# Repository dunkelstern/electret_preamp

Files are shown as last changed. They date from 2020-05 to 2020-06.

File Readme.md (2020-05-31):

# Electret Microphone Preamp

This design is purely based on [Texas Instruments Single-Supply, Electret Microphone Pre-Amplifier Reference Design by John Caldwell](http://www.ti.com/lit/ug/tidu765/tidu765.pdf?ts=1590780945605)

The Jupyter notebook is basically a interactive Version of that reference design PDF. I claim no copyright on this.

## What you will find here

### Jupyter Notebook

The included Jupyter Notebook is an interactive version of the reference design PDF from Texas instruments. You can
play with all values and let the program re-calculate all relevant values to be used in your own design.

There are some areas that will be most important:

- Operating Voltage of the Preamp

Operating Voltage

- Parameters of the Microphone capsule in use

Microphone parameters

- Acceptable high-frequency attenuation

Acceptable Attenuation at high frequencies

- Acceptable low-frequency cutoff in output highpass filter

Output capacity

- The List of passive component values

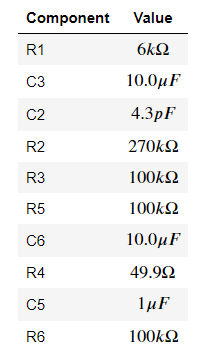
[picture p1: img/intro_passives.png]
Passives


- The Op-Amp parameters to look out for

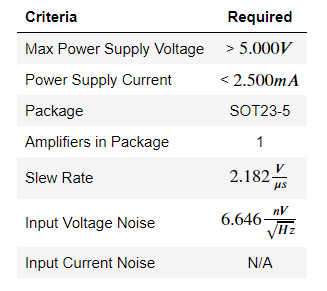
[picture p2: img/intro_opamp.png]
Op-Amp Parameters


### LT Spice simulation

I have simulated the circuit in LTSpice with some different Op-Amps I had in stock.
I deviated from the `270k` resistor in the Op-Amp feedback loop and opted for a `180k` value. This
means the amplification of the Op-Amp will not reach `0dB` (max. seems to be around `-1.8dB`) but the circuit seems
to run more stable at that amplification.

Here are some bode-plots of the frequency response for some tested Op-Amps:

#### OP07

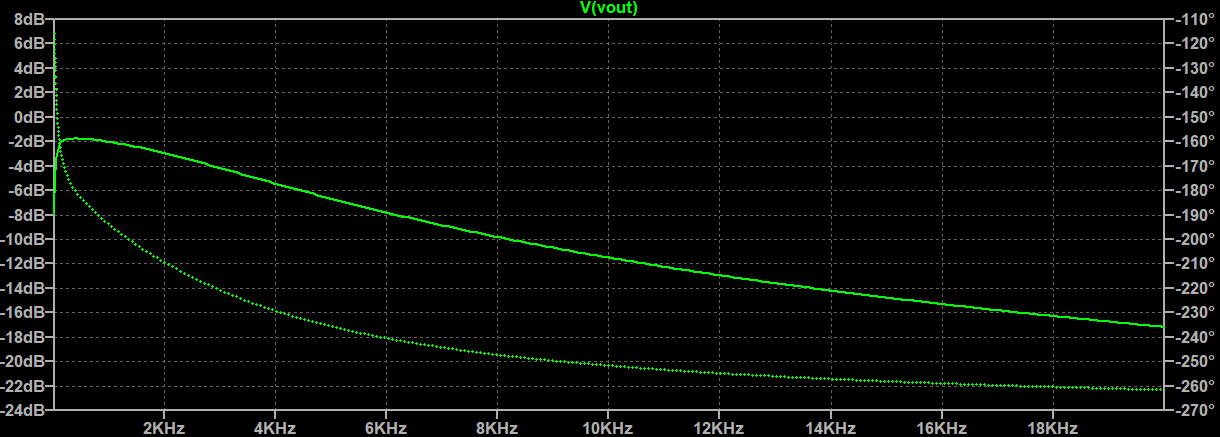
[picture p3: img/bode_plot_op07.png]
Bode plot for OP07


The OP07 is the worst possible of the bunch. The bad response is a product of the sub-optimal slew rate of 0.3V per uS.
Additionally this Op-Amp will add noise to the signal as it's input voltage noise is around . Ideally
it should be below  as we can see in the calulations.

#### TL072

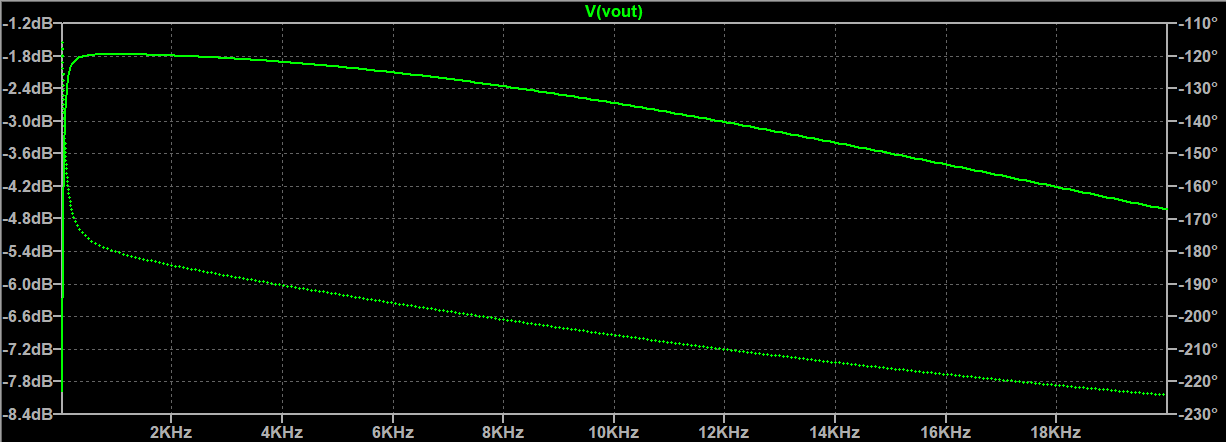
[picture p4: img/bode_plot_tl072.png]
Bode plot for TL072


The TL072 is a bit better than the OP07. The slew rate of 16V/uS is at least enough.
This Op-Amp will add a lot of noise to the signal as it's input voltage noise is around . Ideally
it should be below  as we can see in the calulations.

#### NE5532

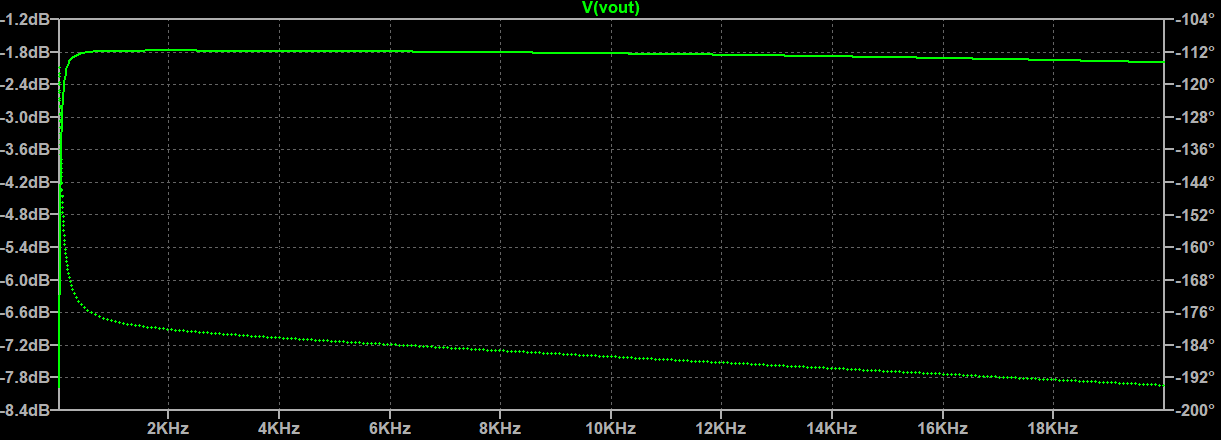
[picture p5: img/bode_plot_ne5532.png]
Bode plot for NE5532


The NE5532 is really good at this. All parameters are within the parameter range we calculated.

#### LM318

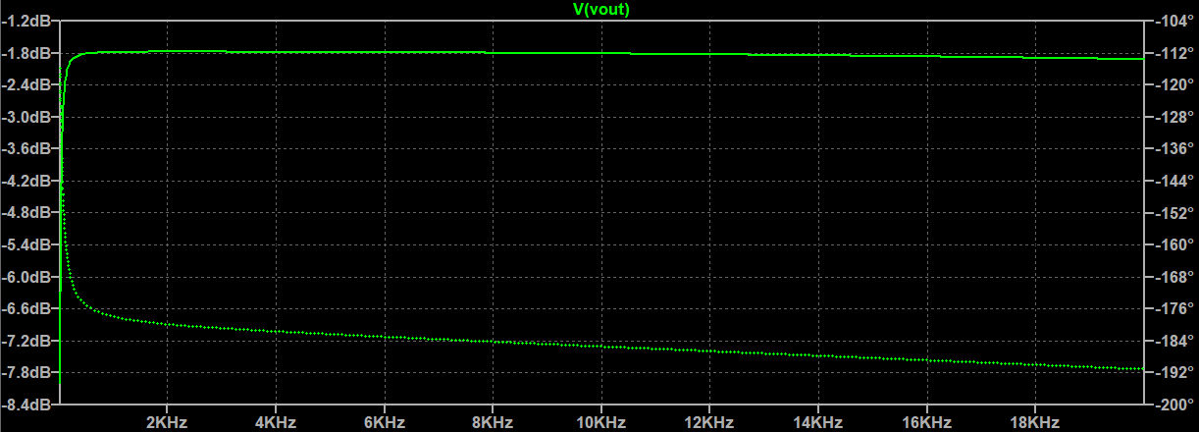
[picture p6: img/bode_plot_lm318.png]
Bode plot for LM318


You can see why the LM318 is used for these applications a lot, as it is a dedicated Audio-Op-Amp the response from
this thing is the best of the bunch.

**Attention**: The `LM318` needed `5.3V` operating voltage to actually do anything in the simulation, I have not
verified if this is an artifact of the simulation or an actual problem!

### KiCAD design

The KiCAD design is based on surface mount components to save as much space as possible. You could use tantalum
capacitors instead of the electrolyte I used here, but they are expensive and I don't have them in stock.

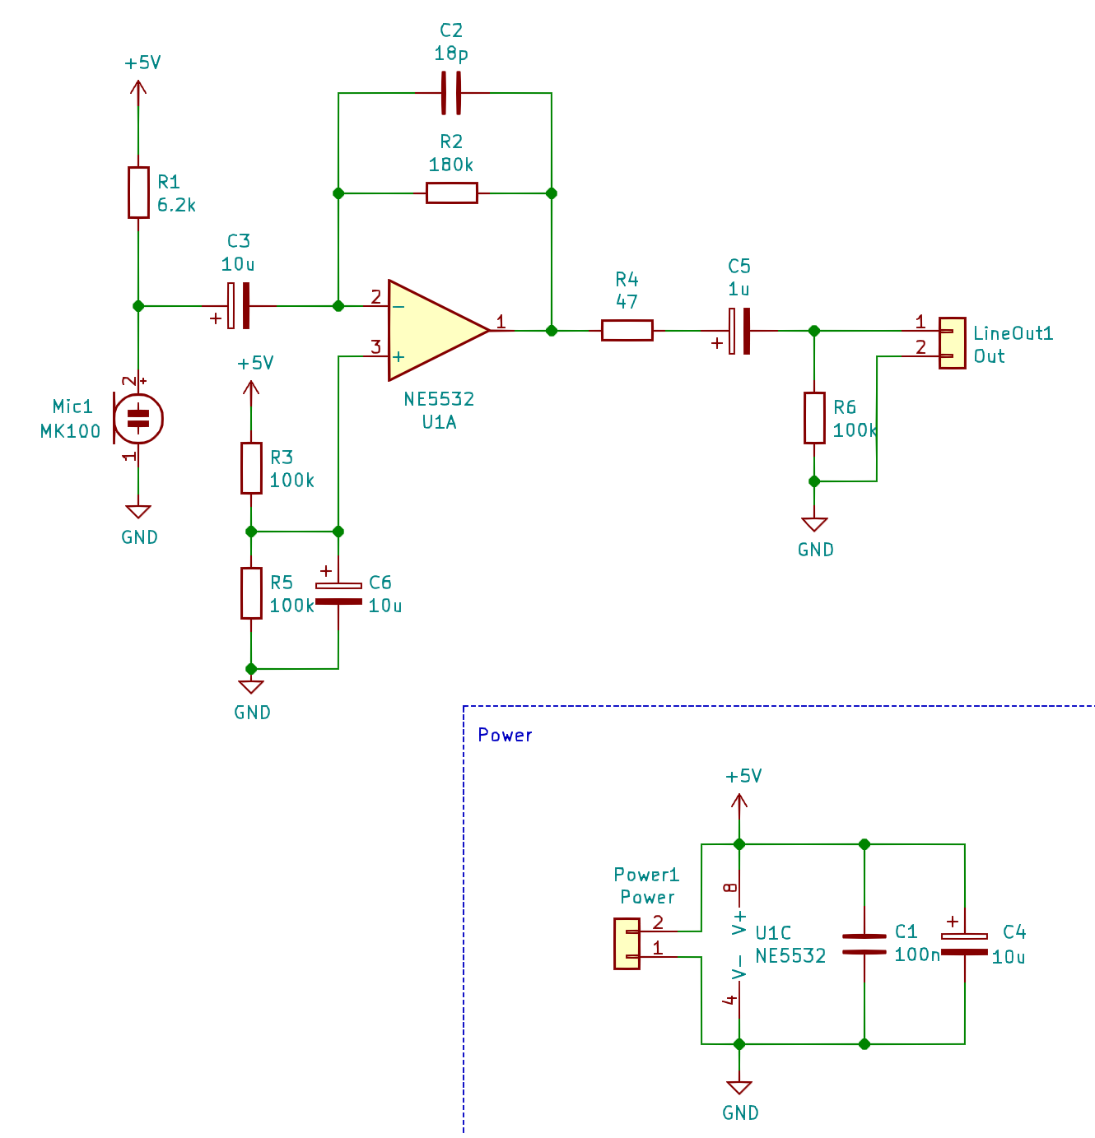
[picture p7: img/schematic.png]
KiCAD schematic


The board design is optimized for space and to be single sided as it is easier to prototype this way.
I will probably add a better two sided design in the future which will be optimized for noise performance and
will probably get even smaller (but I have to order the PCBs then)

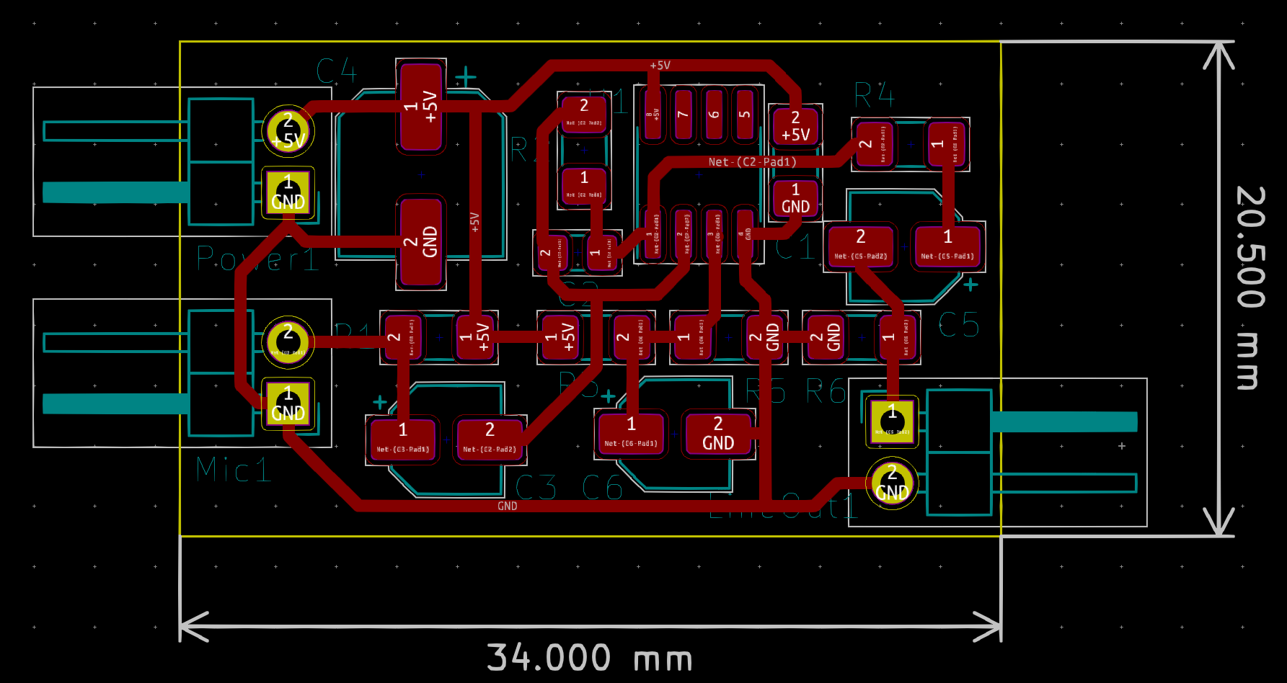
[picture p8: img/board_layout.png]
KiCAD board layout


This is what the board looks like rendered, I will add a photo of the finished product when I have built one.

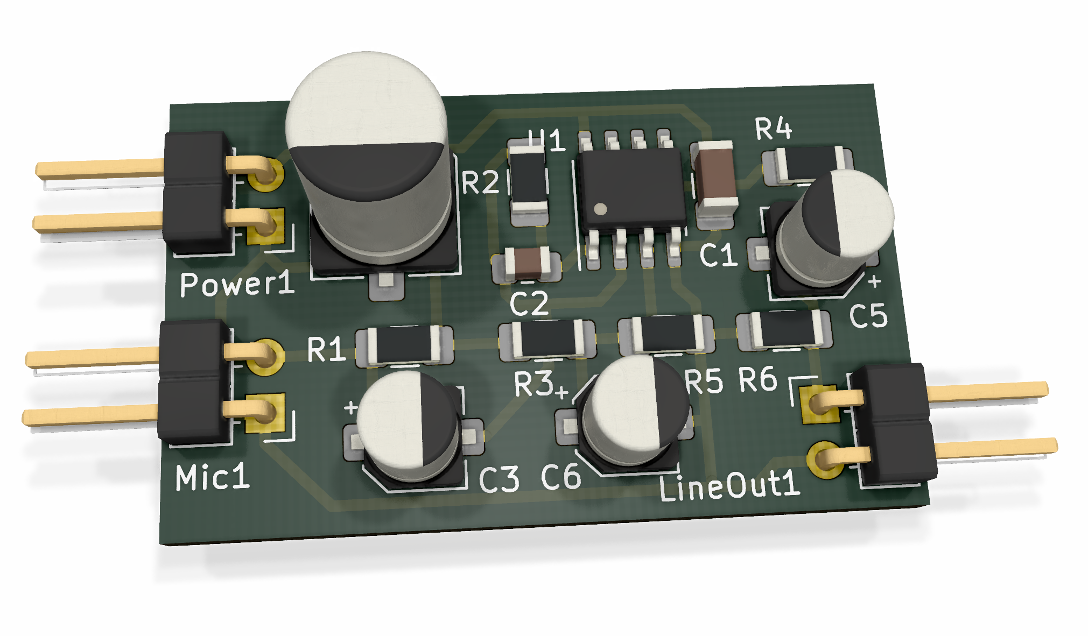
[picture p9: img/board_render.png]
KiCAD board render


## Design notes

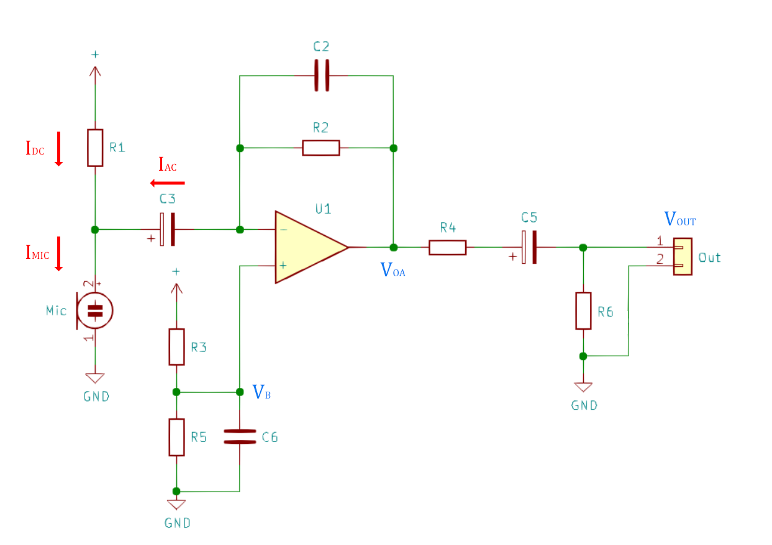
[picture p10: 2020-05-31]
img/schematic_novalues.png

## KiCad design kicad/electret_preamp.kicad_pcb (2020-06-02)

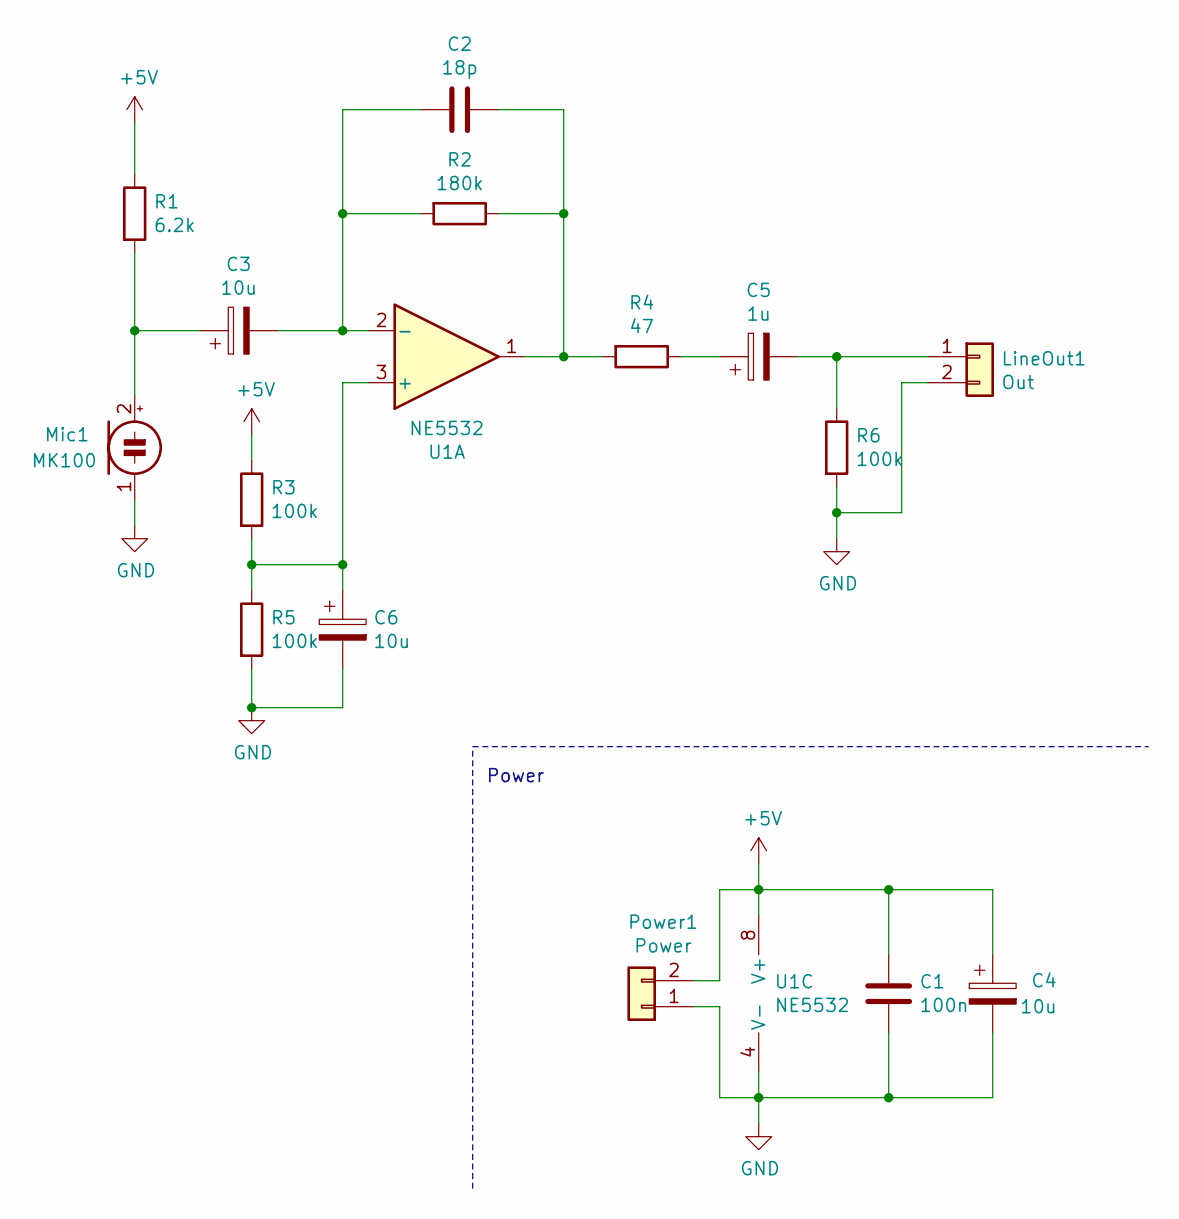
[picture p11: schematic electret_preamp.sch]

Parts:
C1: 100n; C_1210_3225Metric_Pad1.42x2.65mm_HandSolder
C2: 18p; C_0805_2012Metric_Pad1.15x1.40mm_HandSolder
C3, C6: 10u; CP_Elec_4x5.8
C4: 10u; CP_Elec_6.3x9.9
C5: 1u; CP_Elec_4x5.8
LineOut1: Out; PinHeader_1x02_P2.54mm_Horizontal
Mic1: MK100; PinHeader_1x02_P2.54mm_Horizontal
Power1: Power; PinHeader_1x02_P2.54mm_Horizontal
R1: 6.2k; R_1210_3225Metric_Pad1.42x2.65mm_HandSolder
R2: 180k; R_1210_3225Metric_Pad1.42x2.65mm_HandSolder
R3, R5, R6: 100k; R_1210_3225Metric_Pad1.42x2.65mm_HandSolder
R4: 47; R_1210_3225Metric_Pad1.42x2.65mm_HandSolder
U1: NE5532; SOIC-8_3.9x4.9mm_P1.27mm

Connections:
+5V: C1.2, C4.1, Power1.2, R1.1, R3.1, U1.8 (V+)
GND: C1.1, C4.2, C6.2, LineOut1.2, Mic1.1 (-), Power1.1, R5.2, R6.2, U1.4 (V-)
unnamed: C2.1, R2.1, R4.2, U1.1
unnamed: C2.2, C3.2, R2.2, U1.2 (-)
unnamed: C3.1, Mic1.2 (+), R1.2
unnamed: C5.1, R4.1
unnamed: C5.2, LineOut1.1, R6.1
unnamed: C6.1, R3.2, R5.1, U1.3 (+)

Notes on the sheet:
Power

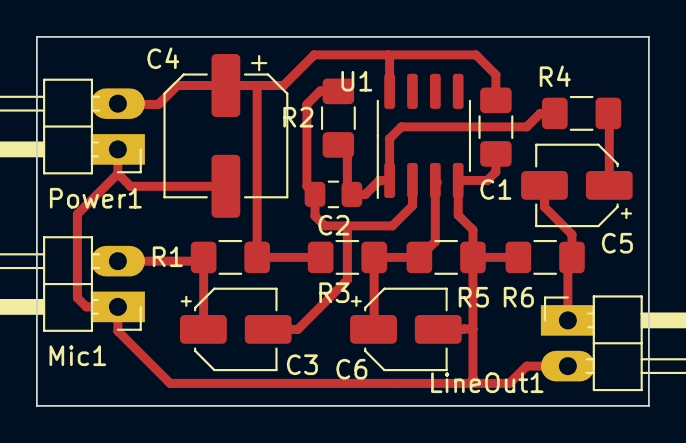
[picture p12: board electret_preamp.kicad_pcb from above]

Board: 2 copper layers, 34.0 x 20.5 mm, 16 parts (0 on the bottom side), 8 nets.

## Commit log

2020-05-31 Board layout (KiCAD)
    [electret_preamp.kicad_pcb, electret_preamp.sch]
2020-05-31 Fix errors in KiCAD files
    [electret_preamp.kicad_pcb, electret_preamp.sch]
2020-05-31 OP-AMP in wrong direction in schematic
2020-05-31 Polarized cap in wrong direction
    [electret_preamp.kicad_pcb, electret_preamp.sch]
2020-06-02 Some layout fixes
    [electret_preamp.kicad_pcb]
